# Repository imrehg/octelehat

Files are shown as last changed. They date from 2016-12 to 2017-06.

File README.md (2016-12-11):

# Overclocking Telemetry HAT

A Raspberry Pi 3 HAT ("Hardware Attached on Top") specially designed for
overclocking.

* Temperature measurement
* Voltage measurement
* I2C connectors for expandability

## License

Released under CERN Open Hardware License 1.2, available at
http://www.ohwr.org/attachments/2388/cern_ohl_v_1_2.txt

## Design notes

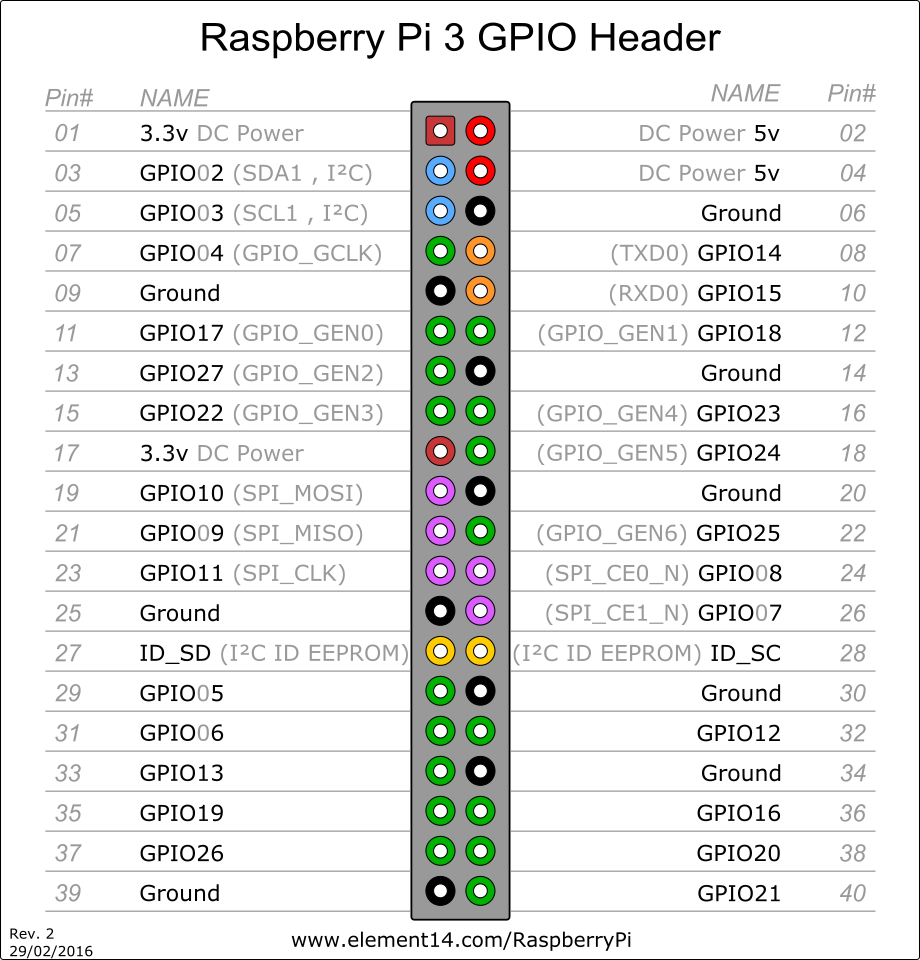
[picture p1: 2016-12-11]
sources/pi3_gpio.png

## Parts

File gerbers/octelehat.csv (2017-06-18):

Part/Designator | Manufacture Part Number/Seeed SKU | Quantity
R4,R8 | 301010196 | 2
R3,R7 | 301010202 | 2
R1,R2,R5,R6 | 301010299 | 4
C5,C11 | 302010006 | 2
C1,C2,C3,C4,C6,C7,C8,C9,C10 | 302010024 | 9
FB1,FB2,FB3,FB4 | 303030001 | 4
J1,J2,J3 | 320110034 | 3
U2 | ADS1015IDGSR | 1
U1,U3 | MAX31855KASA | 2
P1 | REF-182684-02 | 1
P2,P3 | XE-1109-001 | 2

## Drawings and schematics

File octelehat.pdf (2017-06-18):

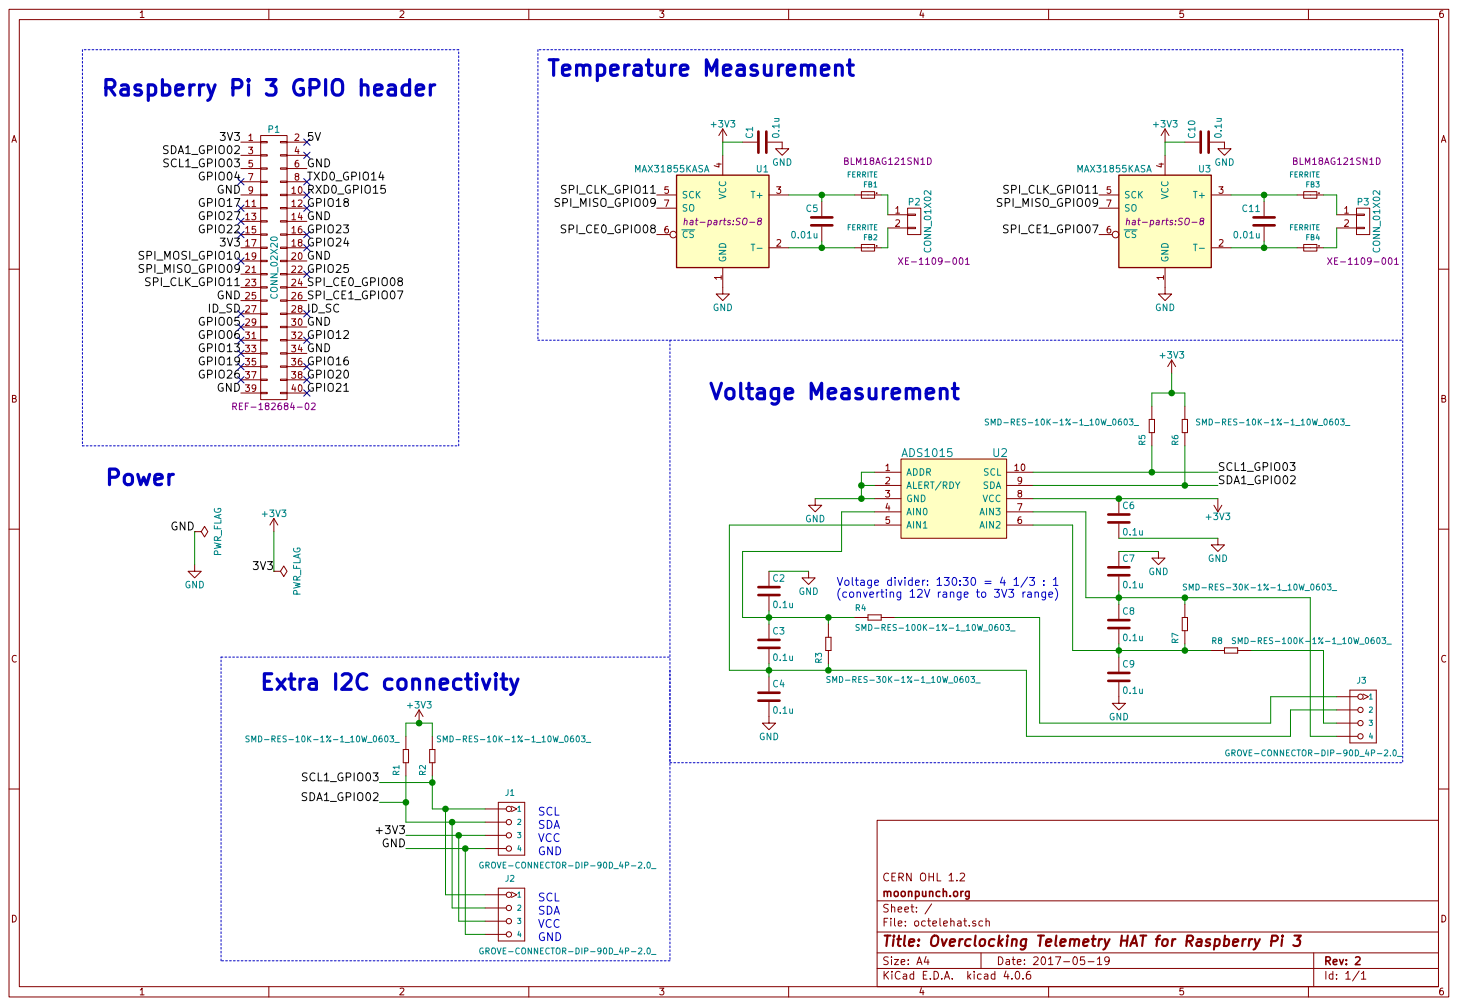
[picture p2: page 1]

(converting 12V range to 3V3 range)

4 J2 GROVE-CONNECTOR-DIP-90D_4P-2.0_ +3V3 GND

File: octelehat.sch Sheet: / moonpunch.org CERN OHL 1.2

Id: 1/1 Title: Overclocking Telemetry HAT for Raspberry Pi 3

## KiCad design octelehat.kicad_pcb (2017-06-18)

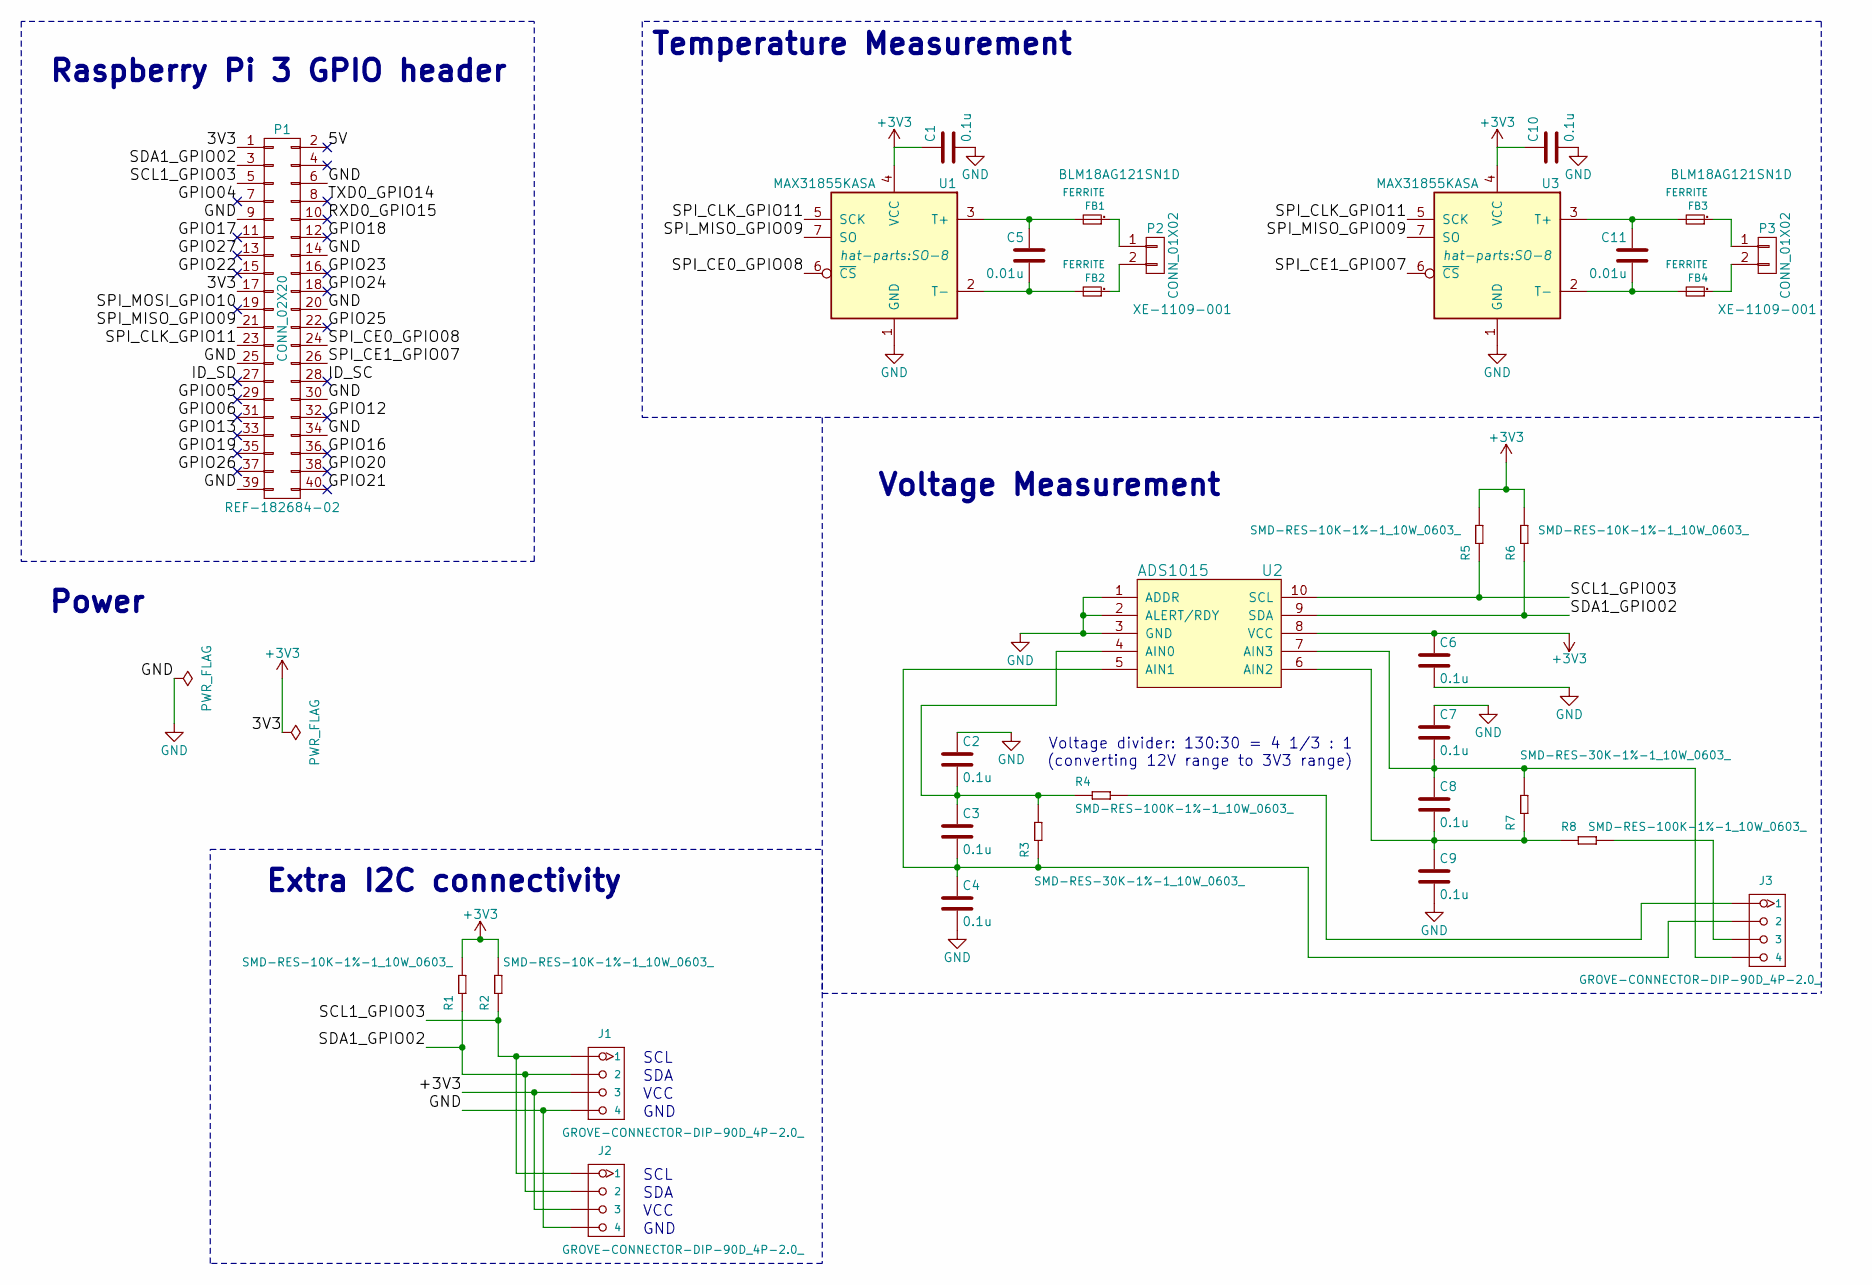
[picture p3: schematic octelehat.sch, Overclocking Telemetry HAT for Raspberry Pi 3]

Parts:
C1, C2, C3, C4, C6, C7, C8, C9, C10: 0.1u; C_0402; MPN CC0402KRX7R8BB104
C5, C11: 0.01u; C_0402; MPN CC0402KRX7R9BB103
FB1, FB2, FB3, FB4: FERRITE; L0603; MPN BLM18AG121SN1D
J1, J2, J3: GROVE-CONNECTOR-DIP-90D_4P-2.0_; HW4-2.0-90D; MPN 1125R-4P
P1: CONN_02X20; Socket_Strip_Straight_2x20_Pitch2.54mm; MPN REF-182684-02
P2, P3: CONN_01X02; Thermocouple; MPN XE-1109-001
R1, R2, R5, R6: SMD-RES-10K-1%-1_10W_0603_; R0603; MPN RC0603FR-0710KL
R3, R7: SMD-RES-30K-1%-1_10W_0603_; MPN RC0603FR-0730KL
R4, R8: SMD-RES-100K-1%-1_10W_0603_; MPN RC0603FR-07100KL
U1, U3: MAX31855KASA; SO-8; MPN MAX31855KASA
U2: ADS1015; TSSOP-10_3x3mm_Pitch0.5mm; MPN ADS1015IDGSR

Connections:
+3V3: C1.1, C6.1, C10.1, J1.3, J2.3, P1.1, P1.17, R1.2, R2.2, R5.2, R6.2, U1.4 (VCC), U2.8 (VCC), U3.4 (VCC)
/5V: P1.2
/GPIO04: P1.7
/GPIO05: P1.29
/GPIO06: P1.31
/GPIO12: P1.32
/GPIO13: P1.33
/GPIO16: P1.36
/GPIO17: P1.11
/GPIO18: P1.12
/GPIO19: P1.35
/GPIO20: P1.38
/GPIO21: P1.40
/GPIO22: P1.15
/GPIO23: P1.16
/GPIO24: P1.18
/GPIO25: P1.22
/GPIO26: P1.37
/GPIO27: P1.13
/ID_SC: P1.28
/ID_SD: P1.27
/RXD0_GPIO15: P1.10
/SCL1_GPIO03: J1.1, J2.1, P1.5, R2.1, R5.1, U2.10 (SCL)
/SDA1_GPIO02: J1.2, J2.2, P1.3, R1.1, R6.1, U2.9 (SDA)
/SPI_CE0_GPIO08: P1.24, U1.6 (~CS~)
/SPI_CE1_GPIO07: P1.26, U3.6 (~CS~)
/SPI_CLK_GPIO11: P1.23, U1.5 (SCK), U3.5 (SCK)
/SPI_MISO_GPIO09: P1.21, U1.7 (SO), U3.7 (SO)
/SPI_MOSI_GPIO10: P1.19
/TXD0_GPIO14: P1.8
GND: C1.2, C2.1, C4.2, C6.2, C7.1, C9.2, C10.2, J1.4, J2.4, P1.6, P1.9, P1.14, P1.20, P1.25, P1.30, P1.34, P1.39, U1.1 (GND), U2.1 (ADDR), U2.2 (ALERT/RDY), U2.3 (GND), U3.1 (GND)
unnamed: C2.2, C3.1, R3.2, R4.1, U2.4 (AIN0)
unnamed: C3.2, C4.1, J3.2, R3.1, U2.5 (AIN1)
unnamed: C5.1, FB1.2, U1.3 (T+)
unnamed: C5.2, FB2.2, U1.2 (T-)
unnamed: C7.2, C8.1, J3.4, R7.2, U2.7 (AIN3)
unnamed: C8.2, C9.1, R7.1, R8.1, U2.6 (AIN2)
unnamed: C11.1, FB3.2, U3.3 (T+)
unnamed: C11.2, FB4.2, U3.2 (T-)
unnamed: FB1.1, P2.1
unnamed: FB2.1, P2.2
unnamed: FB3.1, P3.1
unnamed: FB4.1, P3.2
unnamed: J3.1, R4.2
unnamed: J3.3, R8.2

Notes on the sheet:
Raspberry Pi 3 GPIO header
Extra I2C connectivity
Power
Temperature Measurement
Voltage Measurement
SCL
SDA
VCC
GND
Voltage divider: 130:30 = 4 1/3 : 1 (converting 12V range to 3V3 range)

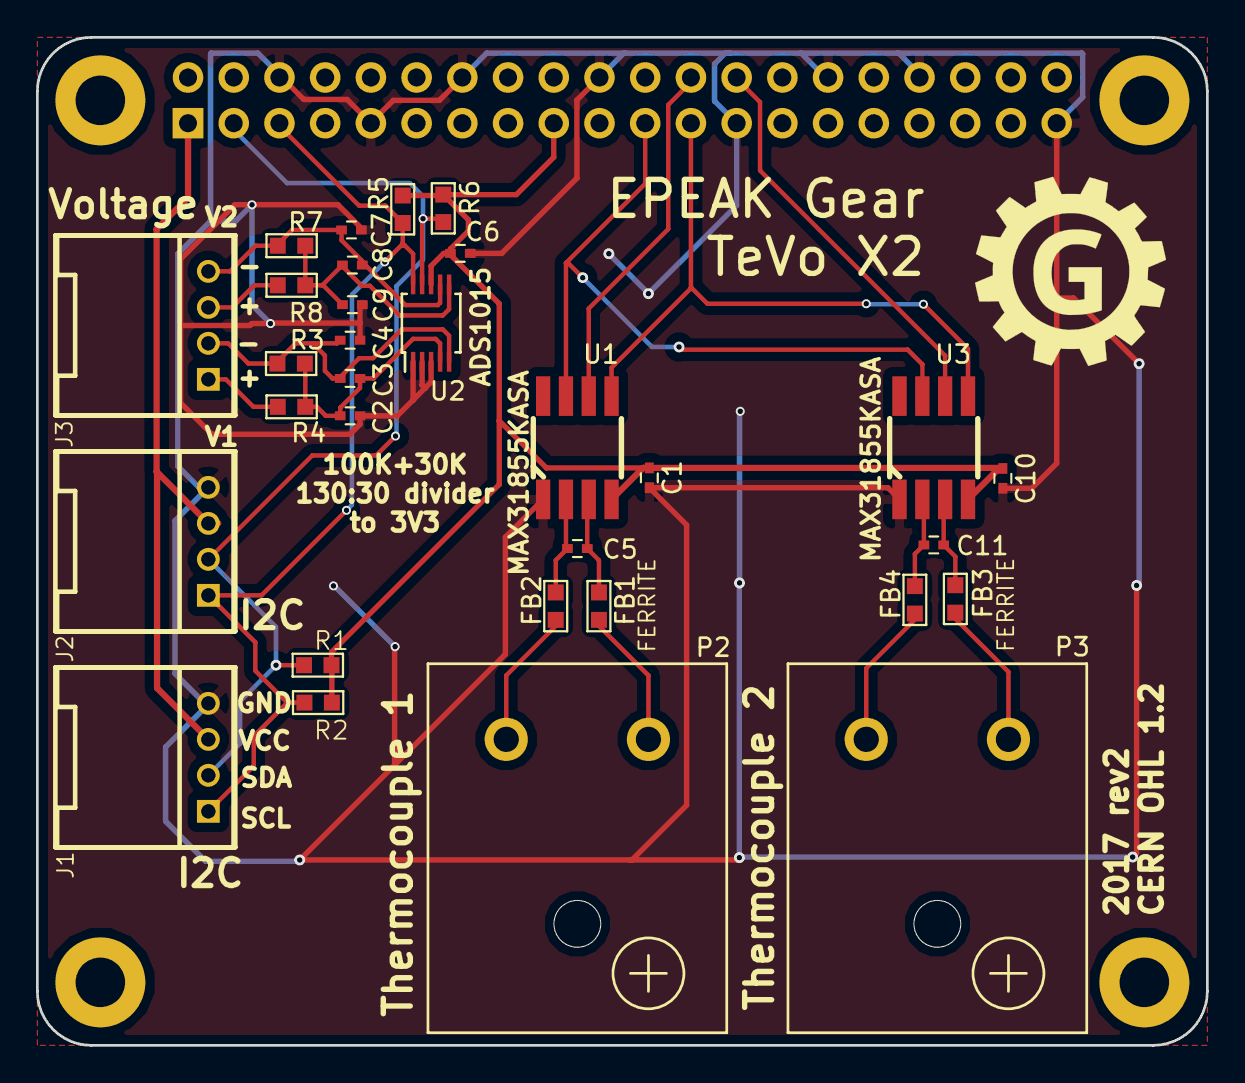
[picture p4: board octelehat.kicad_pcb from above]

Board: 2 copper layers, 65.0 x 56.0 mm, 32 parts (1 on the bottom side), 22 nets.

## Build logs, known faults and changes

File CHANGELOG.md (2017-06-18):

# Change Log

## v0.2.0 - 2017-06-18

* `rev2` preparation
* updated revision string onboard
* replaced part number for 2x20 pin header to have second HAT on top potentially
* revised voltage divider setup, fixing the bug where the divider was actually
  130:100, instead of the required 130:30

## v0.1.0 - 2017-04-10

* `rev1` - first engineering sample production run

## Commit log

2016-12-11 work in progess, schematic
    [octelehat.kicad_pcb, octelehat.sch]
2017-04-05 reassign parts for open parts library
    [octelehat.kicad_pcb, octelehat.sch]
2017-04-05 schematics changes
    [octelehat.sch]
2017-04-05 PCB work in progress
    [octelehat.kicad_pcb]
2017-04-05 adjust design rules
    [octelehat.kicad_pcb]
2017-04-06 work in progress
    [octelehat.kicad_pcb, octelehat.sch]
2017-04-07 rev1 routing
    [octelehat.kicad_pcb, octelehat.sch]
2017-04-10 design update
    [octelehat.kicad_pcb, octelehat.sch]
2017-04-10 add gerbers
    [octelehat.csv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]
2017-05-19 update voltage divider part of circuit
    [octelehat.csv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]
2017-05-19 adding changelog & updating schematics PDF
2017-06-18 updated rev2
    [octelehat.csv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]
